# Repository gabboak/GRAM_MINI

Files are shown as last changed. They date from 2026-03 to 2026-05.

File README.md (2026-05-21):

# GRAM_MINI

*ALPHA VERSION, NOT MEANT FOR PRODUCTION YET.

# Introduction

**GRAM Mini** is a fork of the [GRAM Slim](https://github.com/GRAMCTRL/GRAM-SLIM), a low profile 21-button controller designed for Smash and FGC games. The GRAM MINI retains the same 21-button layout and firmware compatibility as the GRAM Slim, while downsizing the PCB and case design around a smaller, more compact form factor. This project is fully open-source and is intended to be very easy and staight-foward to build .

**This is a community fork and not an official GRAM product. If you would like to support the original designers, consider joining the official [GRAM Digital Controllers Discord server](https://discord.com/invite/6TuHw2r2X4) to recieve updates on the GRAMCTRL teams's new projects.**

![GRAM MINI]()

## Included Files

Included in this repo are all the files needed to build a GRAM MINI:

-  **Gerber files** for PCB fabrication

-  **bom.csv and positions.csv** — for PCBA fabrication

-  **STL/STEP files** for 3D printing the enclosure

-  **KiCad source files** for the PCB design

-  **Case/shell design files** -for the enclosure design

*Note: Firmware is not included in this repository. This controller runs [Haybox-GRAM]([https://github.com/JonnyHaystack/haybox](https://github.com/GRAMCTRL/HayBox-GRAM)). Refer to the Haybox-GRAM documentation for flashing and configuration.*

## Thanks & Acknowledgements

There are several people who made this project possible, either directly or indirectly.

- [GRAMCTRL](https://github.com/GRAMCTRL), that designed the original GRAM Slim that this fork is based on.

- [CarVac](https://github.com/JonnyHaystack), who helped me with designing the GRAM MINI's PCB*

- [TBox](https://linktr.ee/tb0x), who jump-started my interest in making this project.

# Ordering & Customization Guide

For a full walkthrough on ordering PCBs and enclosure, refer to the original GRAM Slim documentation:

Make sure to use the Gerber and position.csv files from **this repository** when placing your order, as the PCB dimensions and component placement differ from the original GRAM Slim.

[GRAM Slim — Ordering & Customization Guide](https://github.com/GRAMCTRL/GRAM-SLIM#ordering--customization-guide)

# Build Guide

## Video Guide

**[Video build guide coming soon](#)**

*Unfortunatley the video guide is not available at the moment, but the link will be updated as soon as it will be uploaded*

## Soldering

Only two components require manual soldering. All other components will be soldered by JLCPCB if you select PCBA.

Before you start, confirm you have the following components:

-  **[Kailh Choc 1350 hotswap sockets](https://a.aliexpress.com/_EzR1QHC)** × 21

-  **[USBC connector](https://a.aliexpress.com/_EzR1QHC)** × 1 *(only if you did **not** select the Standard PCBA option when ordering)*

### Kailh Choc Hotswap Sockets

Solder one socket per button footprint (21 total) on the underside of the PCB.

![]()
![]()

Apply a small amount of solder to one pad first, then hold the socket in place and reflow to tack it before soldering the second pad. A good joint will be shiny and fully cover the socket tab.

### USB-C Connector *(skip if ordered via PCBA)*

The USB-C connector uses SMD pads as well as through-hole pins and requires care to avoid damaging the pads.

For this reason (unless you are very experienced), I suggest soldering the SMD pads using either a ***Hot plate*** or a ***Hot air gun*** and using ***Solder paste***

  -[**hot air gun video guide**](https://www.youtube.com/watch?v=VL5mSLma4D4)
  -[**hot plate video guide**](#)

First of all take your  USBC module and remove the back cover by loosening the side latches and wiggling the back cover as shown in the pictures. this is NOT necessary but recommended to inspect the pins once they have been soldered.
![LOOSEN SIDE LATCHES]()
![WIGGLE BACK FLAP]()
  
After removing the back flap, place a thin layer of solder paste on the SMD pads and place the USBC connector on the board
![SOLDER PASTE]()
![USBC CONNECTOR ON TOP OF SOLDER PASTE]()

Using your soldering method of choiche, solder the SMD pads with the USBC pins
![SOLDERED PADS]()
***-DO NOT WORRY IF THE PIN GROUPS THAT ARE HIGHLIGHTED ARE BRIDGING, AS PINS  AND  ARE UNROUTED-***

Flip the board and using a soldering iron with a CONTROLLABLE TEMPERATURE, fill the through-holes with solder. After you are done use a multimeter to check for bridging between the pins (or just give it an eye test).
![SOLDERED THROUGH-HOLES]()
## Assembly

**Step 1 — Print or source the case**

Using the STL/STEP files in the repo, print or order your shell components. Check the fit with your PCB before proceeding.

**Step 2 — Install the switches**

Place the first top plate on top of the PCB and, while being careful not to bend any pins, orient the switch so as to have the two pins alligned to the socket's holes and press it down firmly into the PCB.
***-MAKE SURE THAT THE POSITION AND NUMBER OF. SWITCHES
YOU INSTALLED CORRESPONDS TO THE ONE OF YOUR PREFERRED TOP PLATE-***

![SWITCH ORIENTATION]()
![SWITCH BEING INSTALLED]()
  -NOTE: this is the perfect time to flash your controller and check if every button works

**Step 3 — Close the enclosure**

Place the topmost plate and the two bottom plates as shown in the image, then insert your  4x 11mm Chicago screws in the designated holes while making sure the flat side is facing upwards and tighten the screws.

![]()

After doing that, install your keycaps by alligning the cross on the keycaps with the cross on you switches and pressing down firmly.

![]()

**Step 6 — Final step**

Enjoy your new controller =)

![]()

---

*This project is licensed under [GPL-3.0](./LICENSE). Based on the [GRAM Slim](https://github.com/GRAMCTRL/GRAM-SLIM) by GRAMCTRL, also licensed under GPL-3.0.*

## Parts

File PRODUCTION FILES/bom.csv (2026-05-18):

Designator | Footprint | Quantity | Value | LCSC Part #
C1, C10, C2, C4 | 402 | 4 | 1uF | C52923
C11, C12, C13, C14, C15, C16, C17, C3, C5, C6 | 402 | 10 | 100nF | C1525
C7, C8 | 402 | 2 | 22pF | C1555
C9 | 402 | 1 | 10uF | C15525
CH1, CH10, CH11, CH12, CH13, CH14, CH15, CH16, CH17, CH18, CH19, CH2, CH20, CH21, CH3, CH4, CH5, CH6, CH7, CH8, CH9 | SW_choc_v1_HS_1u | 21 | choc_SW_HS
D1, D2 | D_SOD-123 | 2 | Schottky Diode | C8598
D3 | 805 | 1 | GREEN | C84256
F1 | 1206 | 1 | 500 mA | C70076
J1 | TYPE-C_24P_QCHT | 1 | USB C Connector | C456013
R1 | 603 | 1 | 1M | C25190
R10, R11 | 402 | 2 | 1k | C11702
R2, R3 | 402 | 2 | 5.1k | C25744
R4 | 402 | 1 | 470 | C25117
R5 | 603 | 1 | 5.6k | C23189
R6 | 603 | 1 | 10k | C25804
R7 | 402 | 1 | 10k | C25744
R8, R9 | 603 | 2 | 27 | C25190
U1 | SOT-23 | 1 | XC6206 | C5446
U2 | SOT-23-6 | 1 | USBLC6-2SC6 | C5250994
U3 | RP2040-QFN-56 | 1 | RP2040 | C2040
U4 | SOIC-8_5.23x5.23mm_P1.27mm | 1 | W25Q128JVS | C97521
Y1 | Crystal_SMD_3225-4Pin_3.2x2.5mm | 1 | 12MHz | C9002
SW1 | SW_SPST_SKQG_WithStem | 1 | Boot | C318884

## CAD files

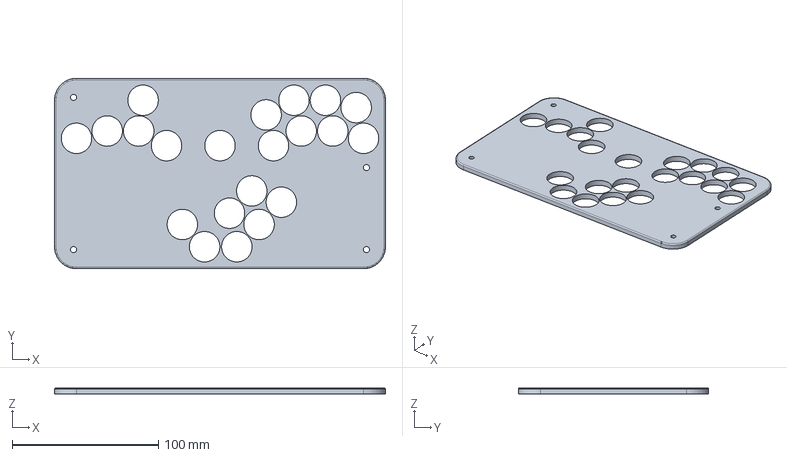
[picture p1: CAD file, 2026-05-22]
3D FILES/top_panel_1.FCStd
226.0 x 130.0 x 4.40 mm

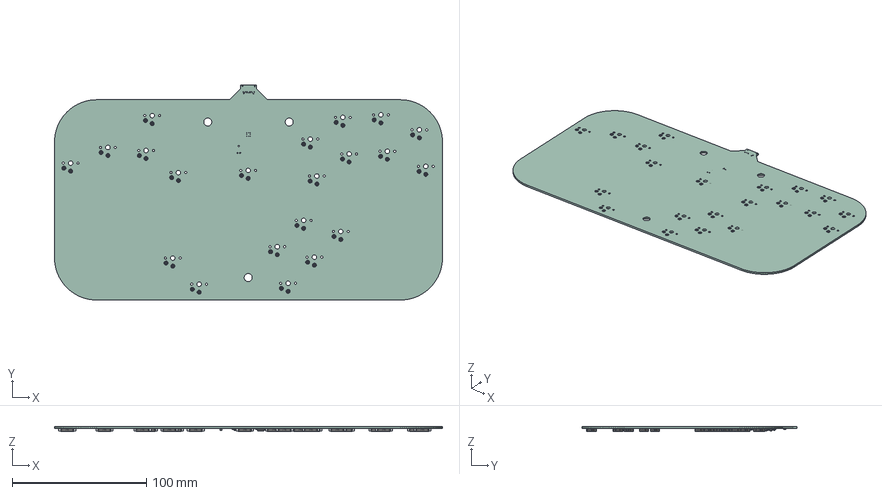
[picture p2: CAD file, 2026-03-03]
KICAD GRAM_MINI_ALPHA/GRAM_MINI_BOTTOM_HOME_ROW.step
288.8 x 160.1 x 3.59 mm
GRAM-SLIM PCB

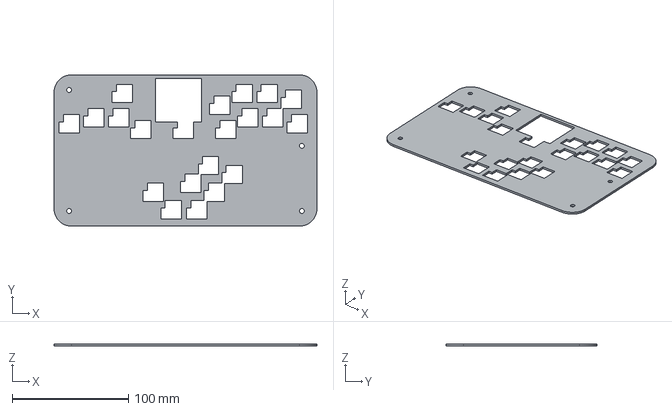
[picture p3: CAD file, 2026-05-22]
PRODUCTION FILES/BOTTOM PANELS/bottom_panel_1.step
226.0 x 130.0 x 1.90 mm

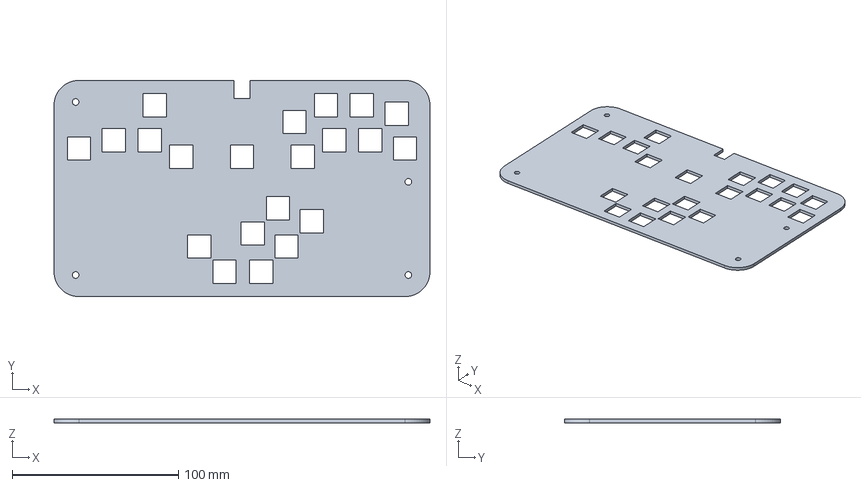
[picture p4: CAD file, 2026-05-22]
3D FILES/top_panel_2.FCStd
226.0 x 130.0 x 2.20 mm

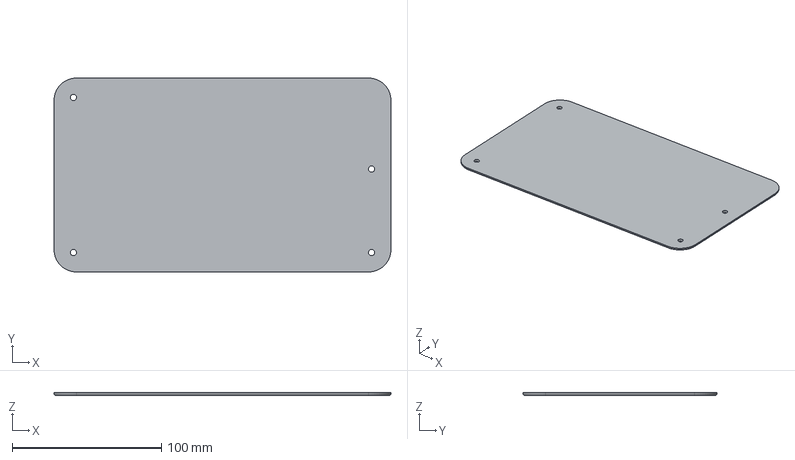
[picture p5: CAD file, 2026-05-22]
PRODUCTION FILES/BOTTOM PANELS/bottom_panel_2.step
226.0 x 130.0 x 1.90 mm

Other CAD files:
PRODUCTION FILES/TOP PANELS/top_panel_1.step
PRODUCTION FILES/TOP PANELS/top_panel_2.step
3D FILES/bottom_panel_2.FCStd
3D FILES/bottom_panel_1.FCStd
PRODUCTION FILES/BOTTOM PANELS/bottom_panel_1.stl
PRODUCTION FILES/BOTTOM PANELS/bottom_panel_2.stl
PRODUCTION FILES/TOP PANELS/top_panel_1.stl
PRODUCTION FILES/TOP PANELS/top_panel_2.stl

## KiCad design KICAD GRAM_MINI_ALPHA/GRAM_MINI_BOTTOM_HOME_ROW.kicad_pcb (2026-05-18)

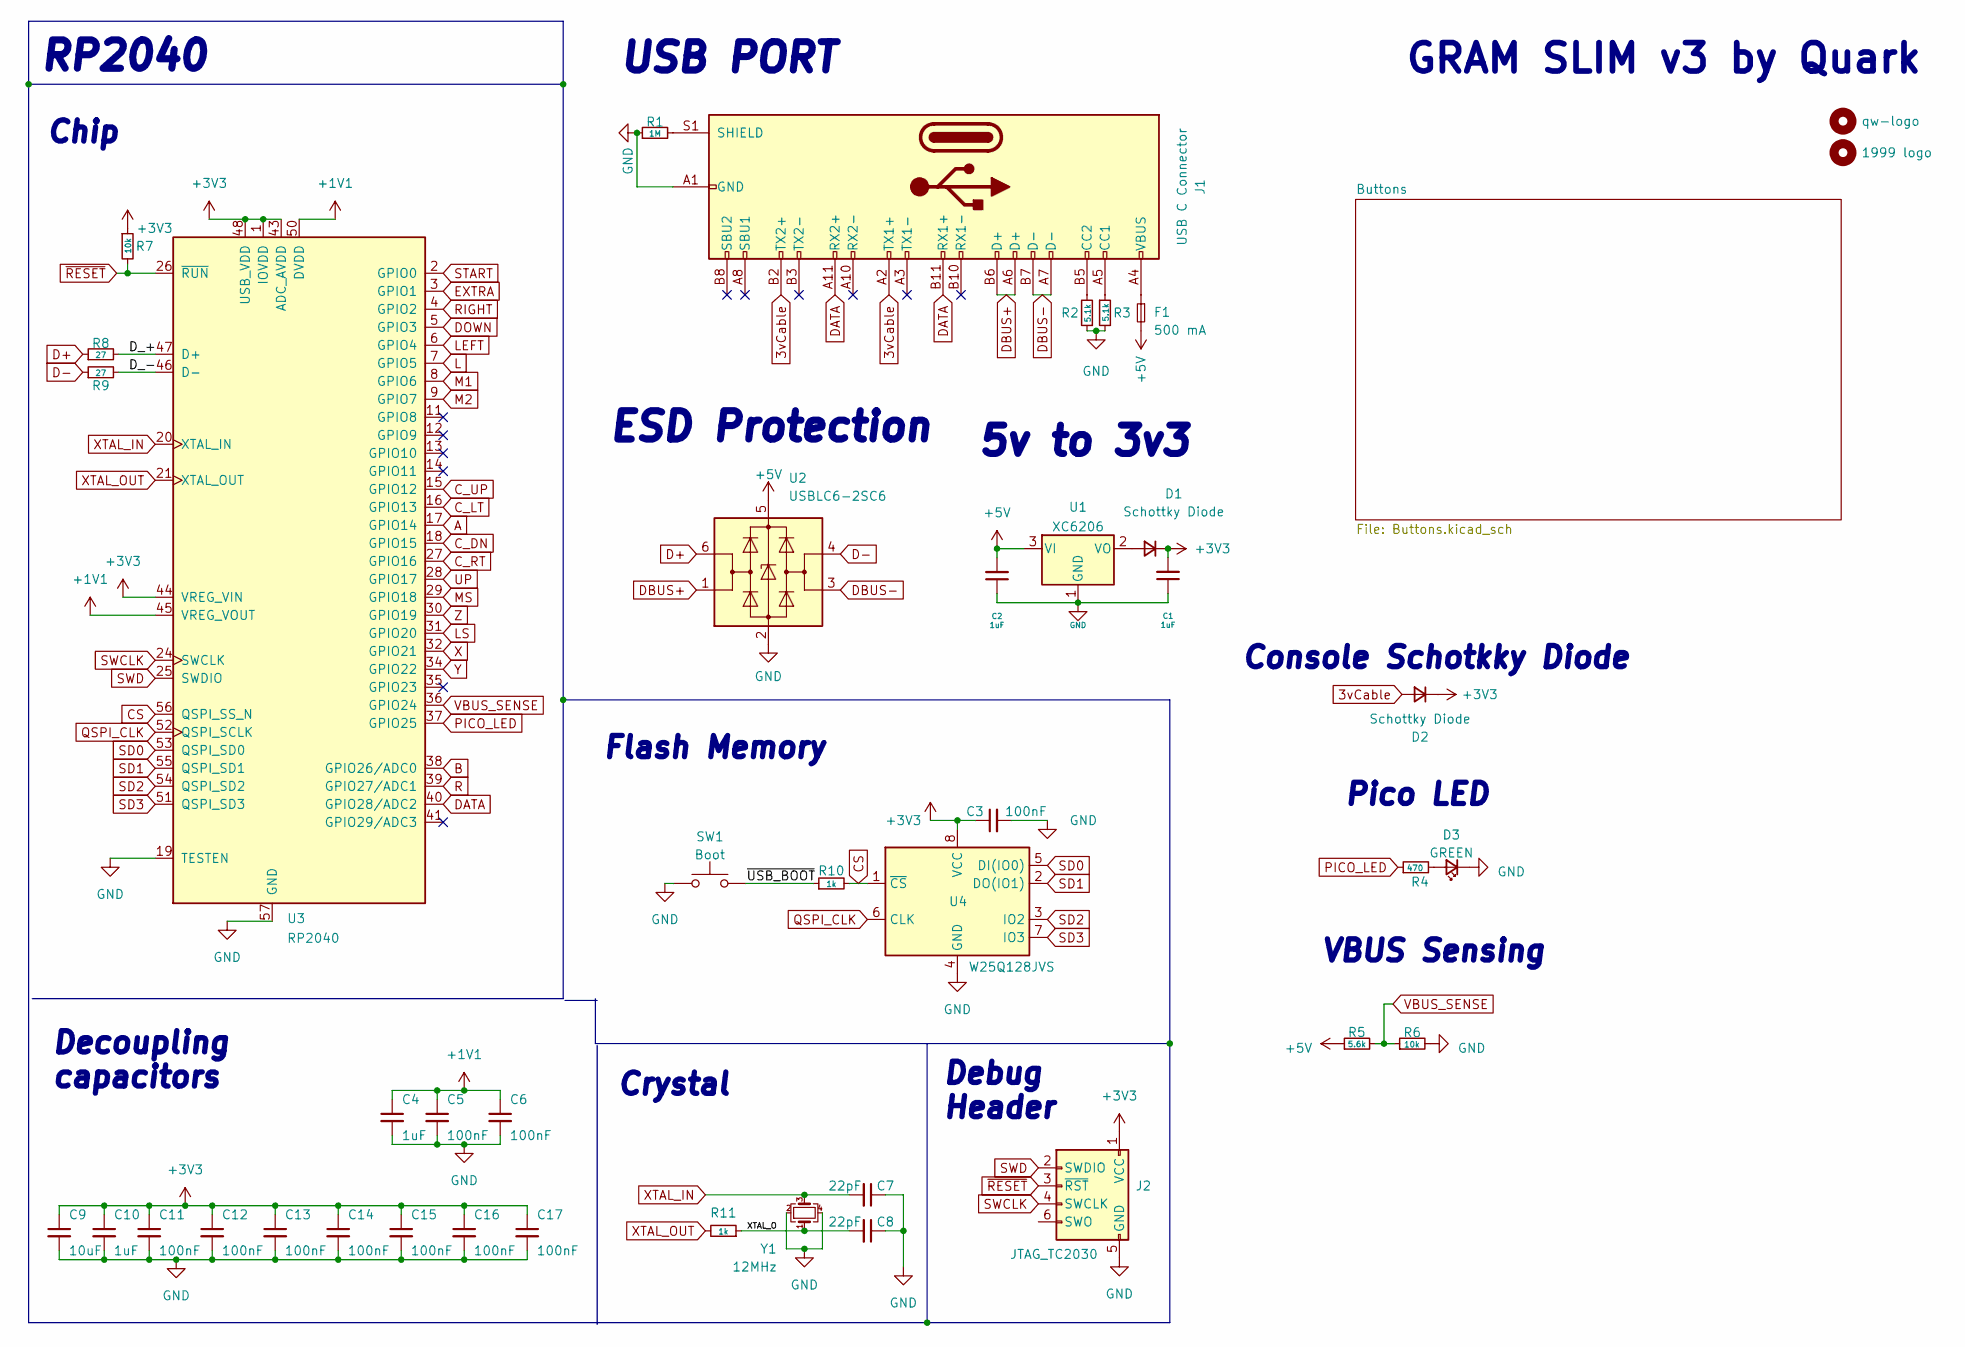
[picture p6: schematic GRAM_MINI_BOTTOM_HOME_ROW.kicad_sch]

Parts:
C1, C2, C4, C10: 1uF; C_0402_1005Metric; LCSC C52923
C3, C5, C6, C11, C12, C13, C14, C15, C16, C17: 100nF; C_0402_1005Metric; LCSC C1525
C7, C8: 22pF; C_0402_1005Metric; LCSC C1555
C9: 10uF; C_0402_1005Metric; LCSC C15525
D1, D2: Schottky Diode; D_SOD-123; LCSC C130880
D3: GREEN; LED_0805_2012Metric
F1: 500 mA; Fuse_1206_3216Metric
H1: qw-logo; qw new logo silk + copper md
H2: 1999 logo; 1999 logo md
J1: USB C Connector; TYPE-C_24P_QCHT; LCSC C456013
J2: JTAG_TC2030; CON_TC2030_outlined
R1: 1M; R_0603_1608Metric; LCSC C25190
R2, R3: 5.1k; R_0402_1005Metric; LCSC C25744
R4: 470; R_0402_1005Metric
R5: 5.6k; R_0603_1608Metric
R6: 10k; R_0603_1608Metric
R7: 10k; R_0402_1005Metric; LCSC C25744
R8, R9: 27; R_0603_1608Metric; LCSC C25190
R10, R11: 1k; R_0402_1005Metric; LCSC C11702
SW1: Boot; SW_SPST_SKQG_WithStem; LCSC C5156480
U1: XC6206; SOT-23; LCSC C5446
U2: USBLC6-2SC6; SOT-23-6
U3: RP2040; RP2040-QFN-56; LCSC C2040
U4: W25Q128JVS; SOIC-8_5.23x5.23mm_P1.27mm; LCSC C97521
Y1: 12MHz; Crystal_SMD_3225-4Pin_3.2x2.5mm; LCSC C9002

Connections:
3vCable: D2.2 (A), J1.A2 (TX1+), J1.B2 (TX2+)
+1V1: C4.1, C5.1, C6.1, U3.23 (DVDD), U3.45 (VREG_VOUT), U3.50 (DVDD)
+3V3: C1.2, C3.1, C9.1, C10.1, C11.1, C12.1, C13.1, C14.1, C15.1, C16.1, C17.1, D1.1 (K), D2.1 (K), J2.1 (VCC), R7.1, U3.1 (IOVDD), U3.10 (IOVDD), U3.22 (IOVDD), U3.33 (IOVDD), U3.42 (IOVDD), U3.43 (ADC_AVDD), U3.44 (VREG_VIN), U3.48 (USB_VDD), U3.49 (IOVDD), U4.8 (VCC)
+5V: C2.2, F1.2, R5.1, U1.3 (VI), U2.5 (VBUS)
/D_+: R8.2, U3.47 (D+)
/D_-: R9.2, U3.46 (D-)
/XTAL_O: C8.2, R11.1, Y1.1
/~USB_BOOT: R10.1, SW1.2
A: U3.17 (GPIO14); also elsewhere on the board
B: U3.38 (GPIO26/ADC0); also elsewhere on the board
CS: R10.2, U3.56 (QSPI_SS_N), U4.1 (~CS)
C_DN: U3.18 (GPIO15); also elsewhere on the board
C_LT: U3.16 (GPIO13); also elsewhere on the board
C_RT: U3.27 (GPIO16); also elsewhere on the board
C_UP: U3.15 (GPIO12); also elsewhere on the board
D+: R8.1, U2.6 (I/O1)
D-: R9.1, U2.4 (I/O2)
DATA: J1.A11 (RX2+), J1.B11 (RX1+), U3.40 (GPIO28/ADC2)
DBUS+: J1.A6 (D+), J1.B6 (D+), U2.1 (I/O1)
DBUS-: J1.A7 (D-), J1.B7 (D-), U2.3 (I/O2)
DOWN: U3.5 (GPIO3); also elsewhere on the board
EXTRA: U3.3 (GPIO1); also elsewhere on the board
GND: C1.1, C2.1, C3.2, C4.2, C5.2, C6.2, C7.1, C8.1, C9.2, C10.2, C11.2, C12.2, C13.2, C14.2, C15.2, C16.2, C17.2, D3.1 (K), J1.A1 (GND), J1.A12 (GND), J1.B1 (GND), J1.B12 (GND), J2.5 (GND), R1.1, R2.1, R3.2, R6.2, SW1.1, U1.1 (GND), U2.2 (GND), U3.19 (TESTEN), U3.57 (GND), U4.4 (GND), Y1.2, Y1.4; also elsewhere on the board
L: U3.7 (GPIO5); also elsewhere on the board
LEFT: U3.6 (GPIO4); also elsewhere on the board
LS: U3.31 (GPIO20); also elsewhere on the board
M1: U3.8 (GPIO6); also elsewhere on the board
M2: U3.9 (GPIO7); also elsewhere on the board
MS: U3.29 (GPIO18); also elsewhere on the board
unnamed: D1.2 (A), U1.2 (VO)
unnamed: D3.2 (A), R4.2
unnamed: F1.1, J1.A4 (VBUS), J1.A9 (VBUS), J1.B4 (VBUS), J1.B9 (VBUS)
unnamed: J1.A5 (CC1), R3.1
unnamed: J1.B5 (CC2), R2.2
unnamed: J1.S1 (SHIELD), R1.2
PICO_LED: R4.1, U3.37 (GPIO25)
QSPI_CLK: U3.52 (QSPI_SCLK), U4.6 (CLK)
R: U3.39 (GPIO27/ADC1); also elsewhere on the board
RIGHT: U3.4 (GPIO2); also elsewhere on the board
SD0: U3.53 (QSPI_SD0), U4.5 (DI(IO0))
SD1: U3.55 (QSPI_SD1), U4.2 (DO(IO1))
SD2: U3.54 (QSPI_SD2), U4.3 (IO2)
SD3: U3.51 (QSPI_SD3), U4.7 (IO3)
START: U3.2 (GPIO0); also elsewhere on the board
SWCLK: J2.4 (SWCLK), U3.24 (SWCLK)
SWD: J2.2 (SWDIO), U3.25 (SWDIO)
UP: U3.28 (GPIO17); also elsewhere on the board
VBUS_SENSE: R5.2, R6.1, U3.36 (GPIO24)
X: U3.32 (GPIO21); also elsewhere on the board
XTAL_IN: C7.2, U3.20 (XTAL_IN), Y1.3
XTAL_OUT: R11.2, U3.21 (XTAL_OUT)
Y: U3.34 (GPIO22); also elsewhere on the board
Z: U3.30 (GPIO19); also elsewhere on the board
~RESET: J2.3 (~RST), R7.2, U3.26 (~RUN)

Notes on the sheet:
GRAM SLIM v3 by Quark
Flash Memory
5v to 3v3
Pico LED
Crystal
Chip
Console Schotkky Diode
RP2040
VBUS Sensing
Debug Header
USB PORT
ESD Protection
Decoupling capacitors

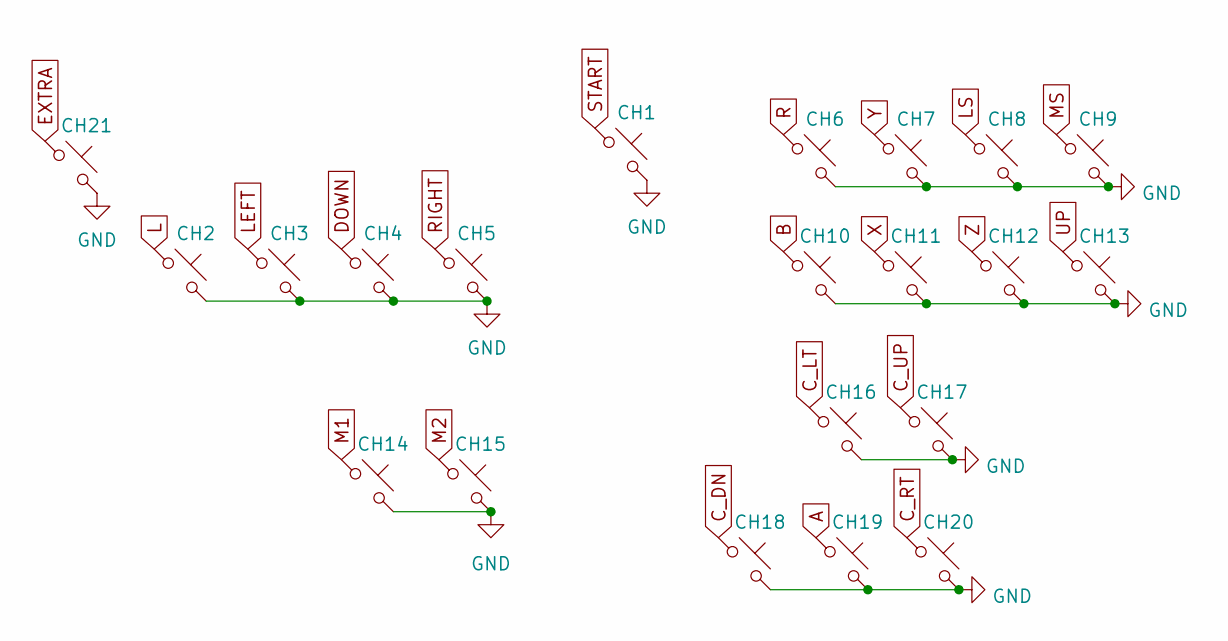
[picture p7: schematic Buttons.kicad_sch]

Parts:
CH1, CH2, CH3, CH4, CH5, CH6, CH7, CH8, CH9, CH10, CH11, CH12, CH13, CH14, CH15, CH16, CH17, CH18, CH19, CH20, CH21: choc_SW_HS; SW_choc_v1_HS_1u

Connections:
A: CH19.1; also elsewhere on the board
B: CH10.1; also elsewhere on the board
C_DN: CH18.1; also elsewhere on the board
C_LT: CH16.1; also elsewhere on the board
C_RT: CH20.1; also elsewhere on the board
C_UP: CH17.1; also elsewhere on the board
DOWN: CH4.1; also elsewhere on the board
EXTRA: CH21.1; also elsewhere on the board
GND: CH1.2, CH2.2, CH3.2, CH4.2, CH5.2, CH6.2, CH7.2, CH8.2, CH9.2, CH10.2, CH11.2, CH12.2, CH13.2, CH14.2, CH15.2, CH16.2, CH17.2, CH18.2, CH19.2, CH20.2, CH21.2; also elsewhere on the board
L: CH2.1; also elsewhere on the board
LEFT: CH3.1; also elsewhere on the board
LS: CH8.1; also elsewhere on the board
M1: CH14.1; also elsewhere on the board
M2: CH15.1; also elsewhere on the board
MS: CH9.1; also elsewhere on the board
R: CH6.1; also elsewhere on the board
RIGHT: CH5.1; also elsewhere on the board
START: CH1.1; also elsewhere on the board
UP: CH13.1; also elsewhere on the board
X: CH11.1; also elsewhere on the board
Y: CH7.1; also elsewhere on the board
Z: CH12.1; also elsewhere on the board

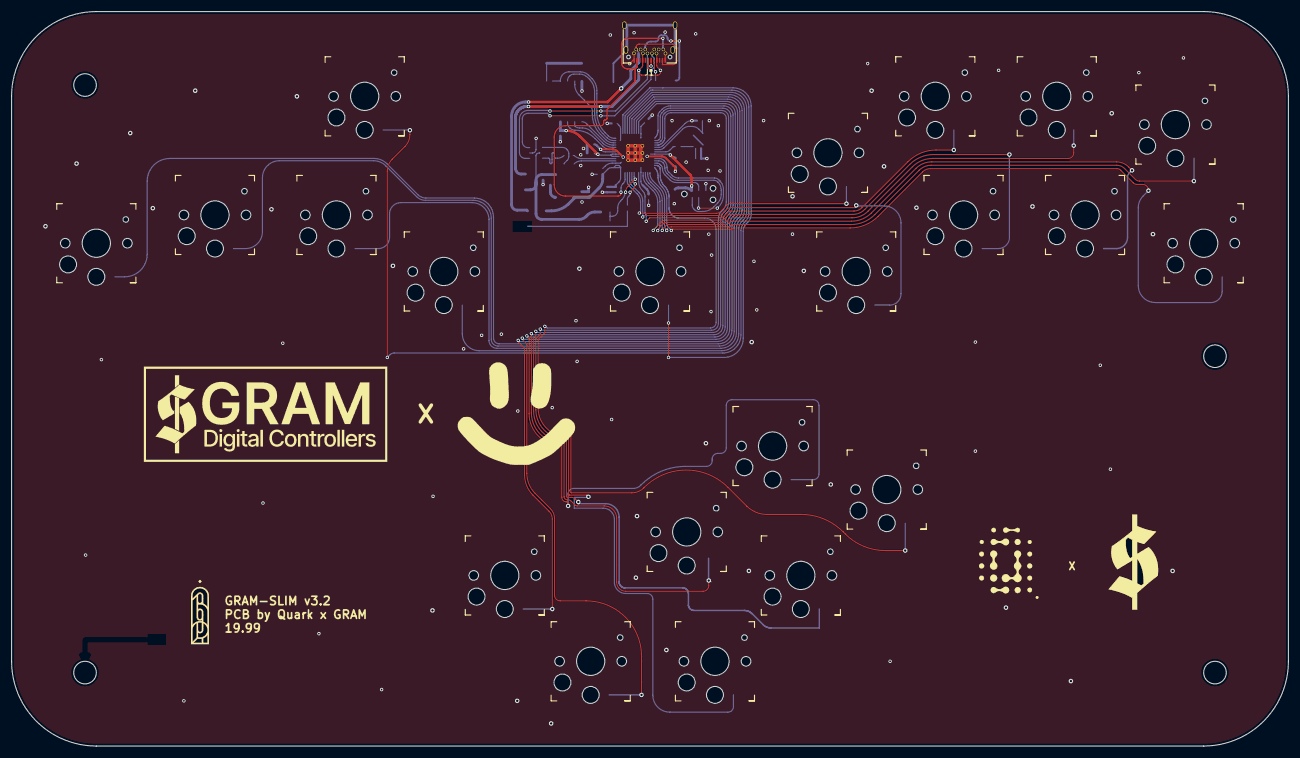
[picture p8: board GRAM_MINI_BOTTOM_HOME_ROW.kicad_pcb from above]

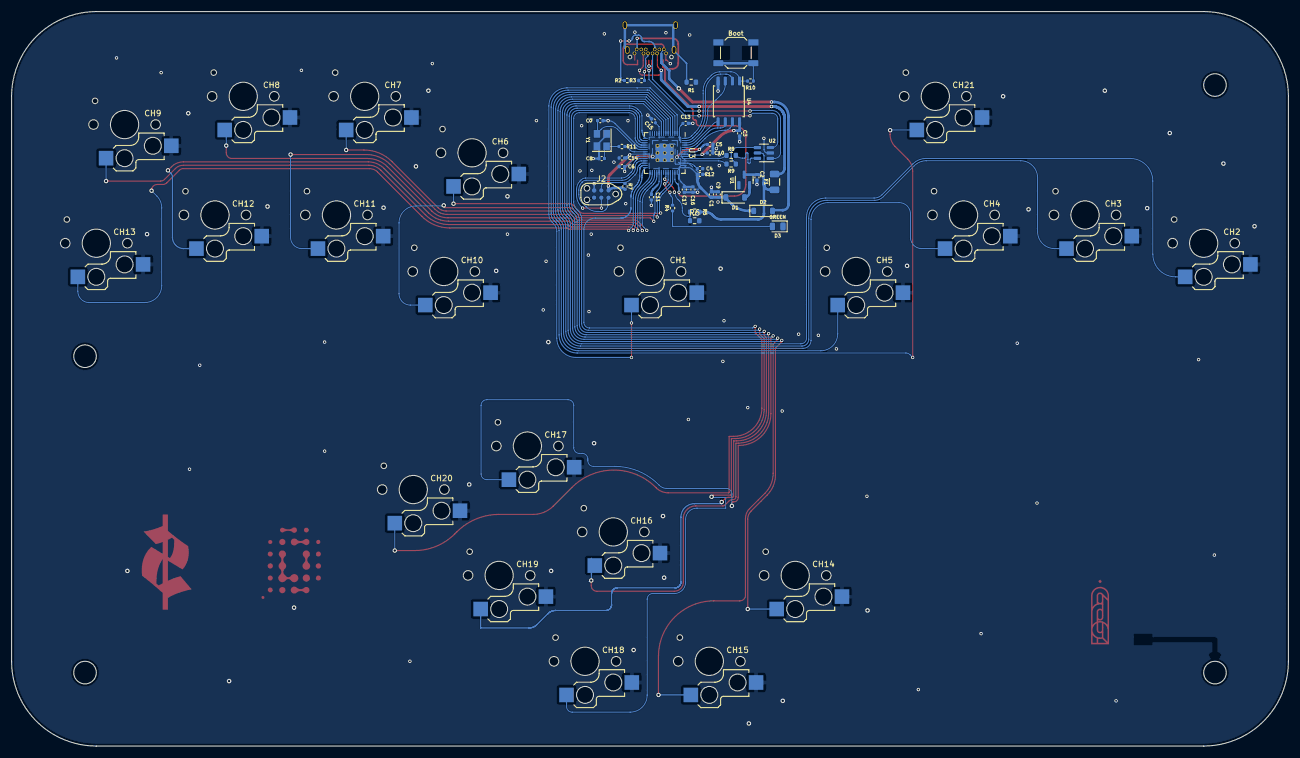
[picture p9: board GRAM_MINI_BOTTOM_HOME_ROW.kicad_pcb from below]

Board: 2 copper layers, 226.0 x 130.0 mm, 63 parts (39 on the bottom side), 54 nets.

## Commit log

2026-03-03 ALPHA KICAD FILES
    alpha release- not at all intended for production
    [Buttons.kicad_sch, GRAM-SLIM_MINI_ALPHA.kicad_pcb, GRAM_MINI_ALPHA.kicad_sch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]
2026-03-07 rename sch and add nc pin
    [GRAM-SLIM_MINI_ALPHA.kicad_sch, GRAM_MINI_ALPHA.kicad_sch]
2026-03-07 flip side of USB connector
    [Buttons.kicad_sch, GRAM-SLIM_MINI_ALPHA.kicad_pcb]
2026-03-07 move resistor that wasn't placed
    [GRAM-SLIM_MINI_ALPHA.kicad_pcb]
2026-05-18 alpha
    pseudo finished alpha commit
    [Buttons.kicad_sch, GRAM-SLIM_MINI_ALPHA.kicad_pcb, GRAM_MINI_BOTTOM_HOME_ROW.kicad_pcb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]
2026-05-19 yac
    yet another commit
    [GRAM-SLIM_MINI_ALPHA.kicad_pcb, bottom_panel_1.FCStd, bottom_panel_1.stl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]
2026-05-22 enclosure
    "final" alpha enclosure dimentions
    [bottom_panel_1.FCStd, bottom_panel_1.step, bottom_panel_1.stl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]
